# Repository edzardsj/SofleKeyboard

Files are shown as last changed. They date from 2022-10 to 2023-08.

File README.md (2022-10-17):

# Sofle Keyboard

## Internal Notes

 - [ ] Enable microcontroller with USB-C (possibly use a specific uC and redo the breakout on the PCB)
 - [ ] Use a scroll wheel (EVQ-WGD001) instead of a rotary encoder ([reference](https://oshwlab.com/ChristAlix/evqwgd001-roll-encoder_carrier-board_copy]) --- [KiCad model](https://github.com/crides/kleeb/blob/master/switch.pretty/EVQWGD001.kicad_mod))  
and add PCB mounting support
 - [ ] Add drilled holes to the PCB for more sophisticated case designs
 - [ ] Check button positioning + scroll wheel positioning / orientation on printed layout
 
 ## Vanilla docs

SofleKeyboard

Sofle is 6×4+5 keys column-staggered split keyboard with encoder support. Based on [Lily58](https://github.com/kata0510/Lily58), [Corne](https://github.com/foostan/crkbd) and [Helix](https://github.com/MakotoKurauchi/helix) keyboards.

**[For more information and documentation visit https://josefadamcik.github.io/SofleKeyboard/](https://josefadamcik.github.io/SofleKeyboard/)**

SofleKeyboard was created by [Josef Adamcik](https://josef-adamcik.cz/). The motivation and process is covered in following blog-post: [Let me introduce you SofleKeyboard - a split keyboard based on Lily58 and Crkbd](https://josef-adamcik.cz/electronics/let-me-introduce-you-sofle-keyboard-split-keyboard-based-on-lily58.html)

Sofle RGB was contributed by [Dane Evans](https://github.com/DaneEvans).

Sofle soldered was contributed by [kb-elmo](https://github.com/kb-elmo)

## Firmware 

Sofle uses [QMK firmware](https://qmk.fm/)

## Default layout 

Default layout for SofleKeyboard

## Images of keyboard

SofleKeyboard

SofleKeyboard Choc

SofleKeyboard PCB

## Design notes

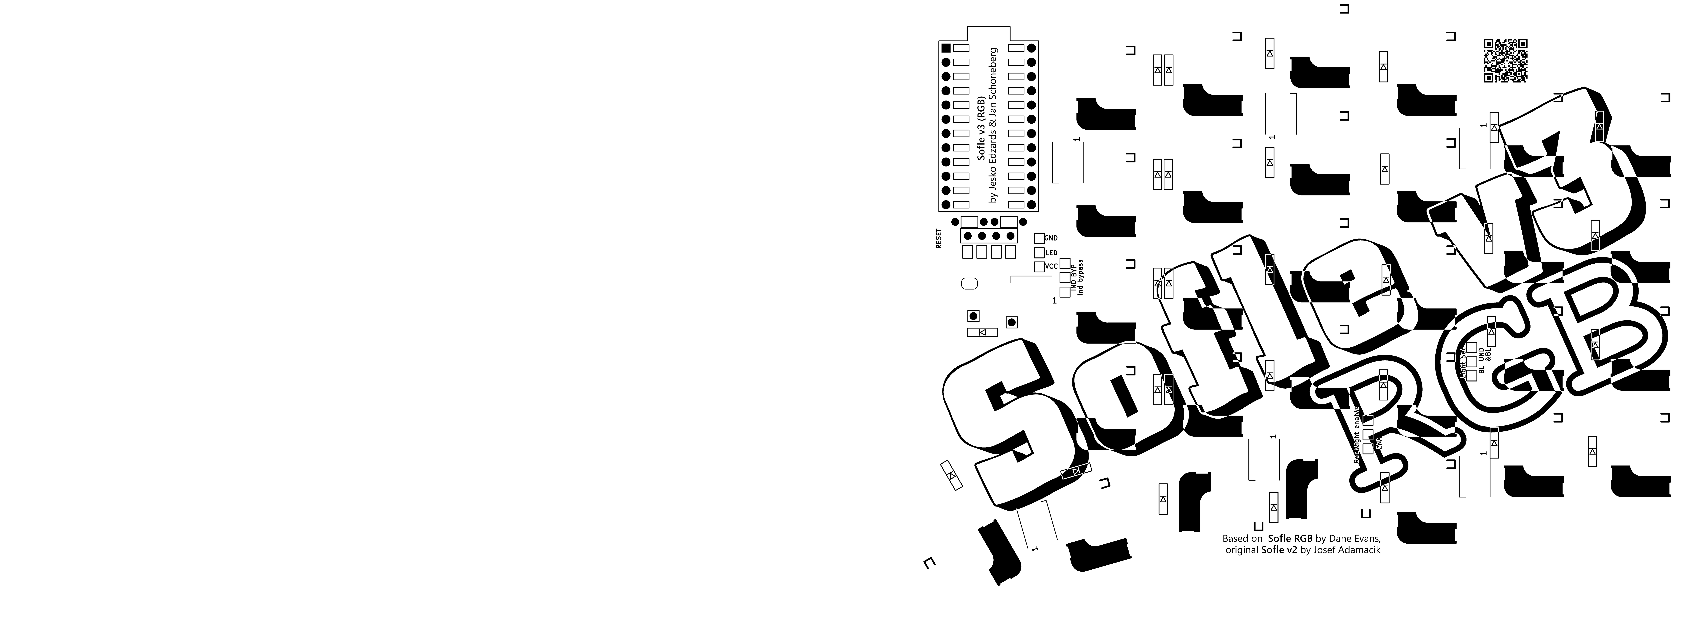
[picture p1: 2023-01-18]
Sofle_v3/silk screen design/Sofle_Front_final.png

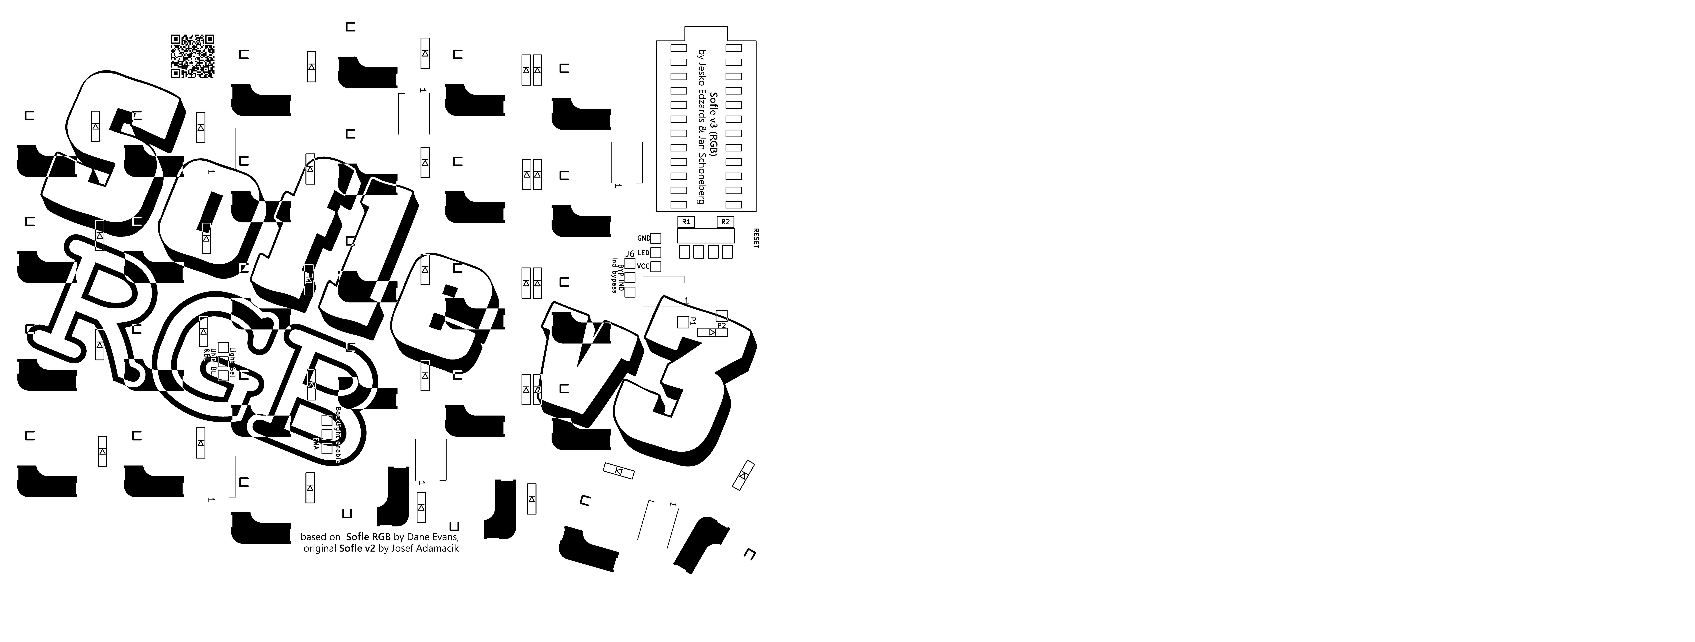
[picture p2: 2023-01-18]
Sofle_v3/silk screen design/Sofle_Back_final.png

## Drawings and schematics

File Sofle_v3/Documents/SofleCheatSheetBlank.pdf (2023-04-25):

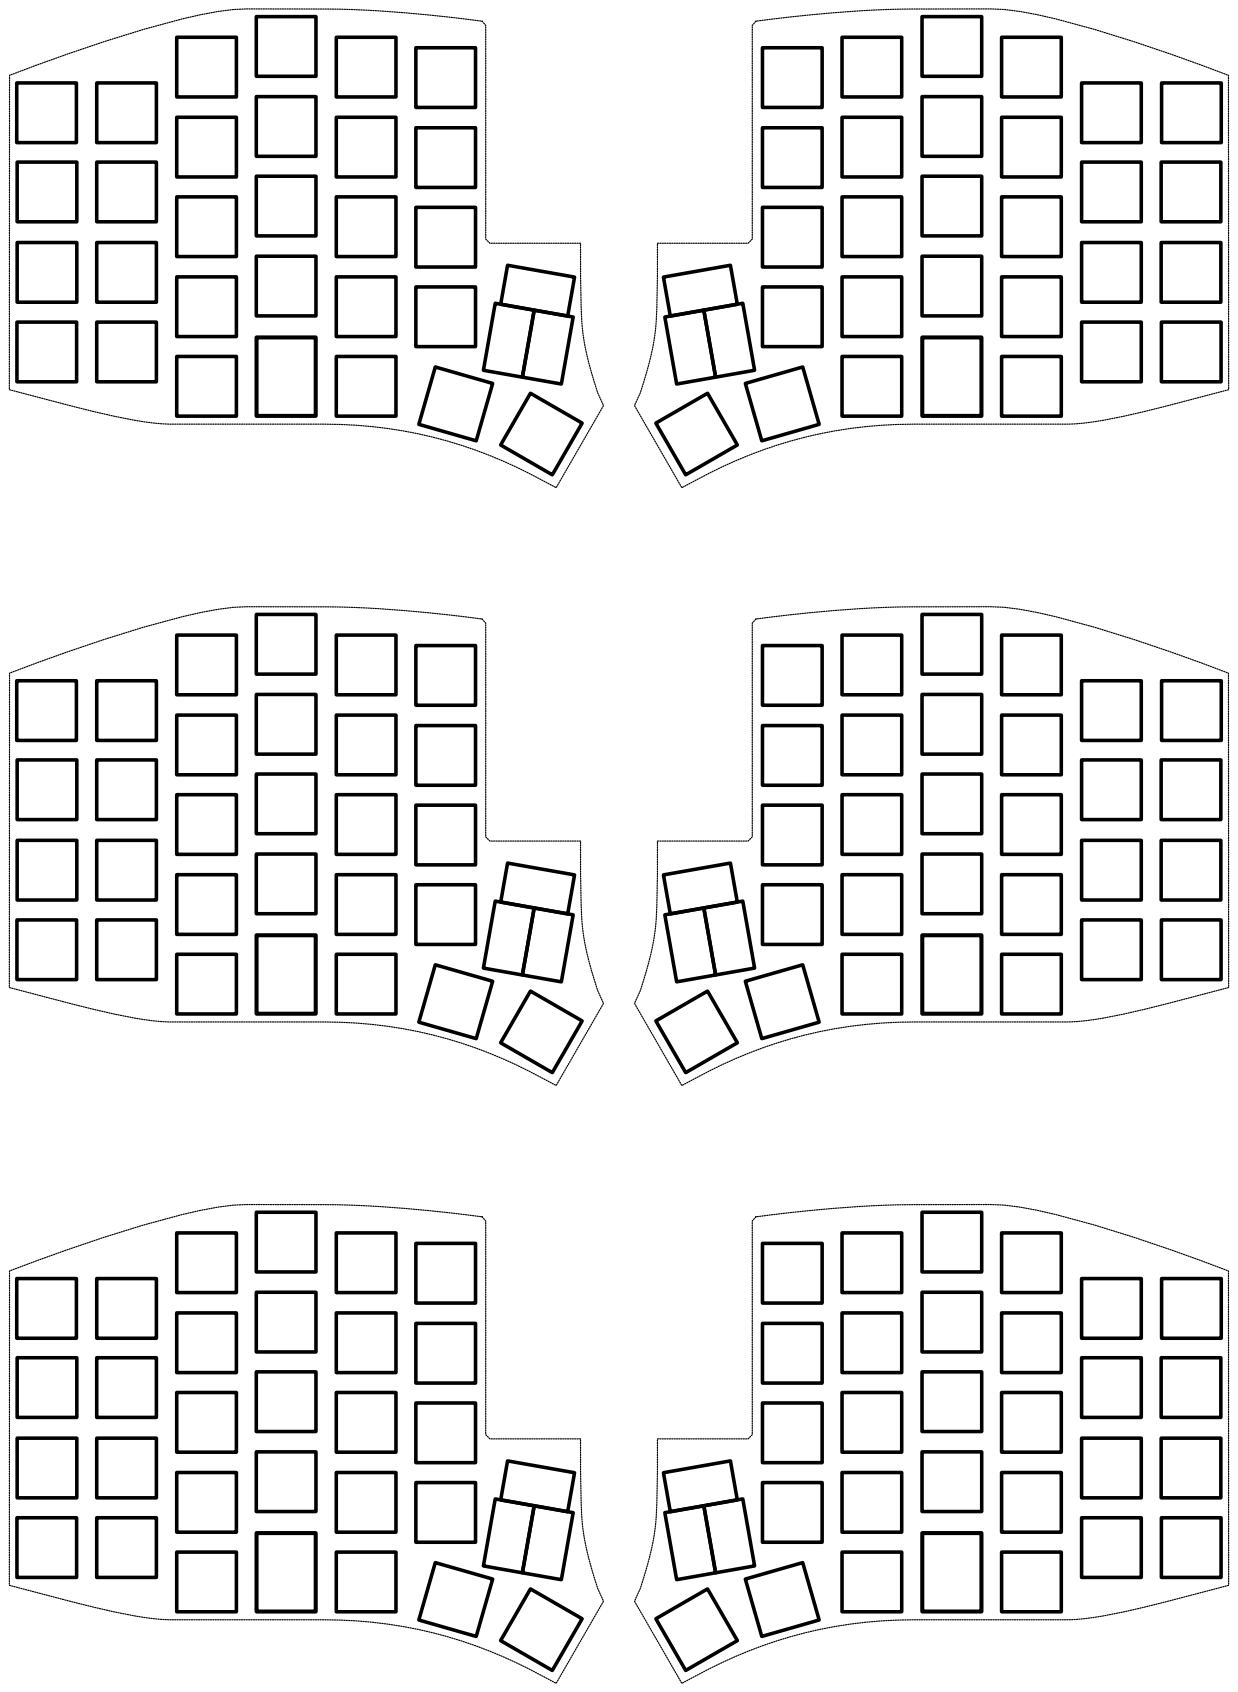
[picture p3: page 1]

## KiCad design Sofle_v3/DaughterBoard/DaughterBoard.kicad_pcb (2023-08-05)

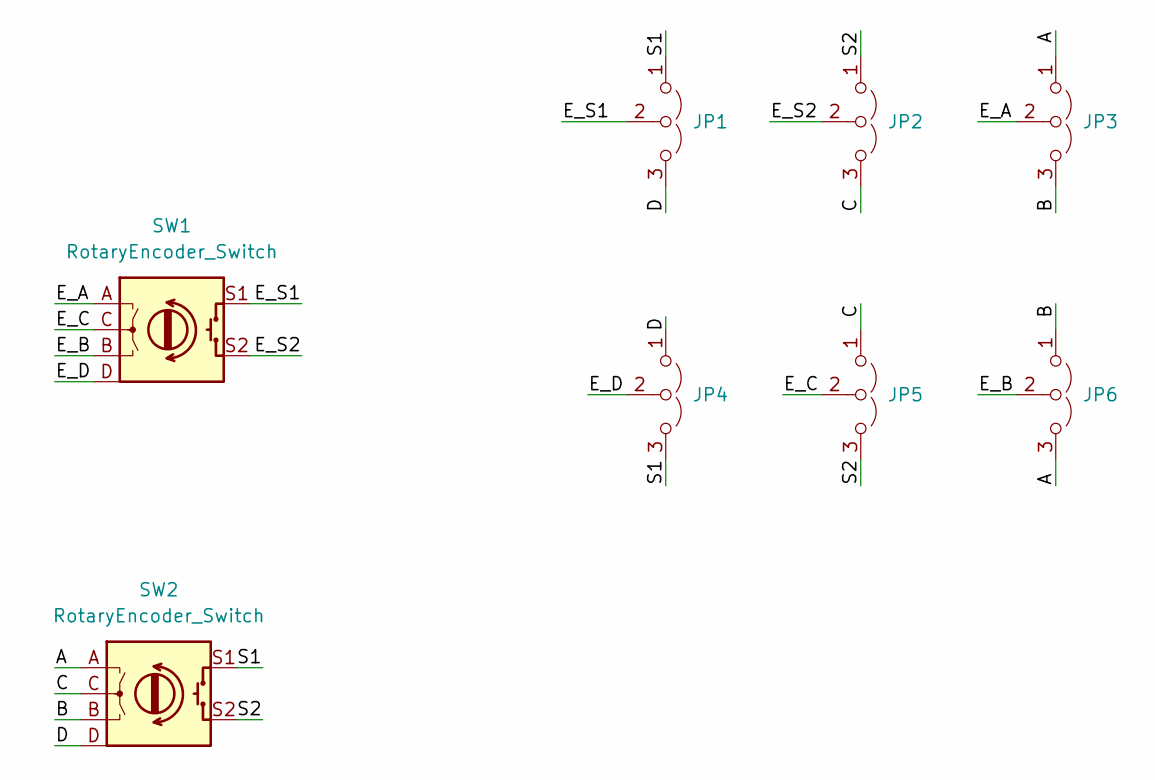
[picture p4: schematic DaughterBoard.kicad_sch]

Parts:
JP1, JP2, JP3, JP4, JP5, JP6: Jumper_3_Open; SolderJumper-3_P1.3mm_Open_Pad1.0x1.5mm
SW1: RotaryEncoder_Switch; EVQWGD001
SW2: RotaryEncoder_Switch; EVQWGD001_DaughterBoard_only

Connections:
/A: JP3.1 (A), JP6.3 (B), SW2.A
/B: JP3.3 (B), JP6.1 (A), SW2.B
/C: JP2.3 (B), JP5.1 (A), SW2.C
/D: JP1.3 (B), JP4.1 (A), SW2.D
/E_A: JP3.2 (C), SW1.A
/E_B: JP6.2 (C), SW1.B
/E_C: JP5.2 (C), SW1.C
/E_D: JP4.2 (C), SW1.D
/E_S1: JP1.2 (C), SW1.S1
/E_S2: JP2.2 (C), SW1.S2
/S1: JP1.1 (A), JP4.3 (B), SW2.S1
/S2: JP2.1 (A), JP5.3 (B), SW2.S2

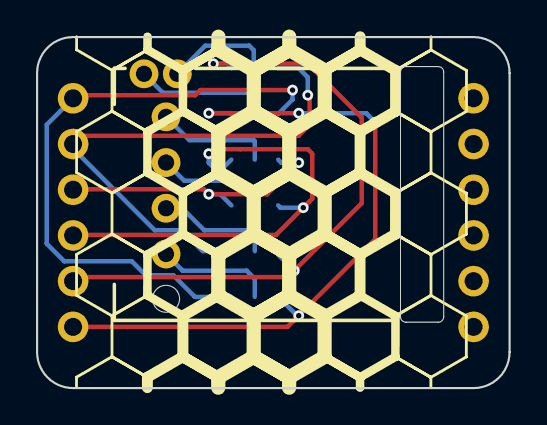
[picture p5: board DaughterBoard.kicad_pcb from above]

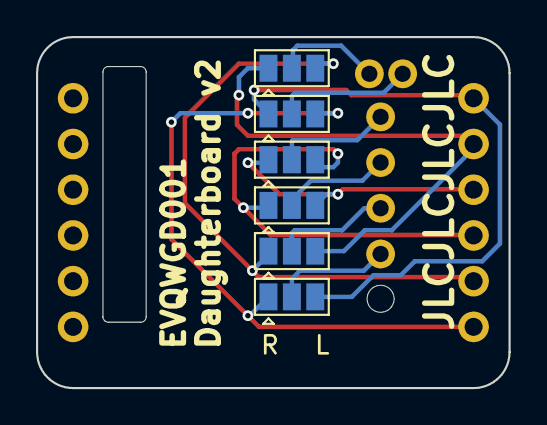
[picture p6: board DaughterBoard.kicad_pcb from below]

Board: 2 copper layers, 26.2 x 19.5 mm, 8 parts (6 on the bottom side), 12 nets.

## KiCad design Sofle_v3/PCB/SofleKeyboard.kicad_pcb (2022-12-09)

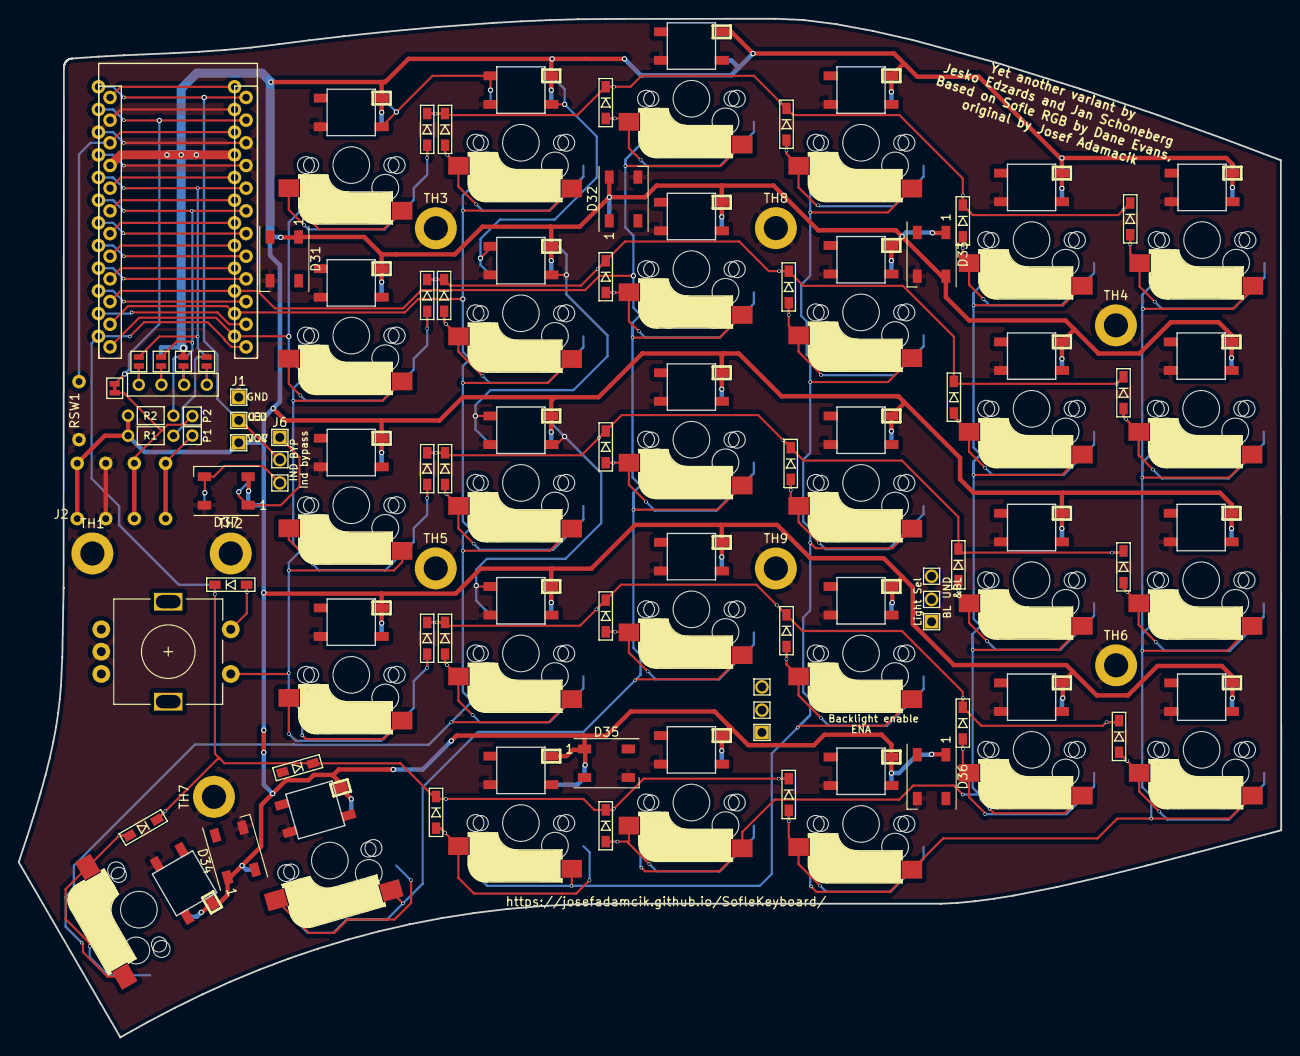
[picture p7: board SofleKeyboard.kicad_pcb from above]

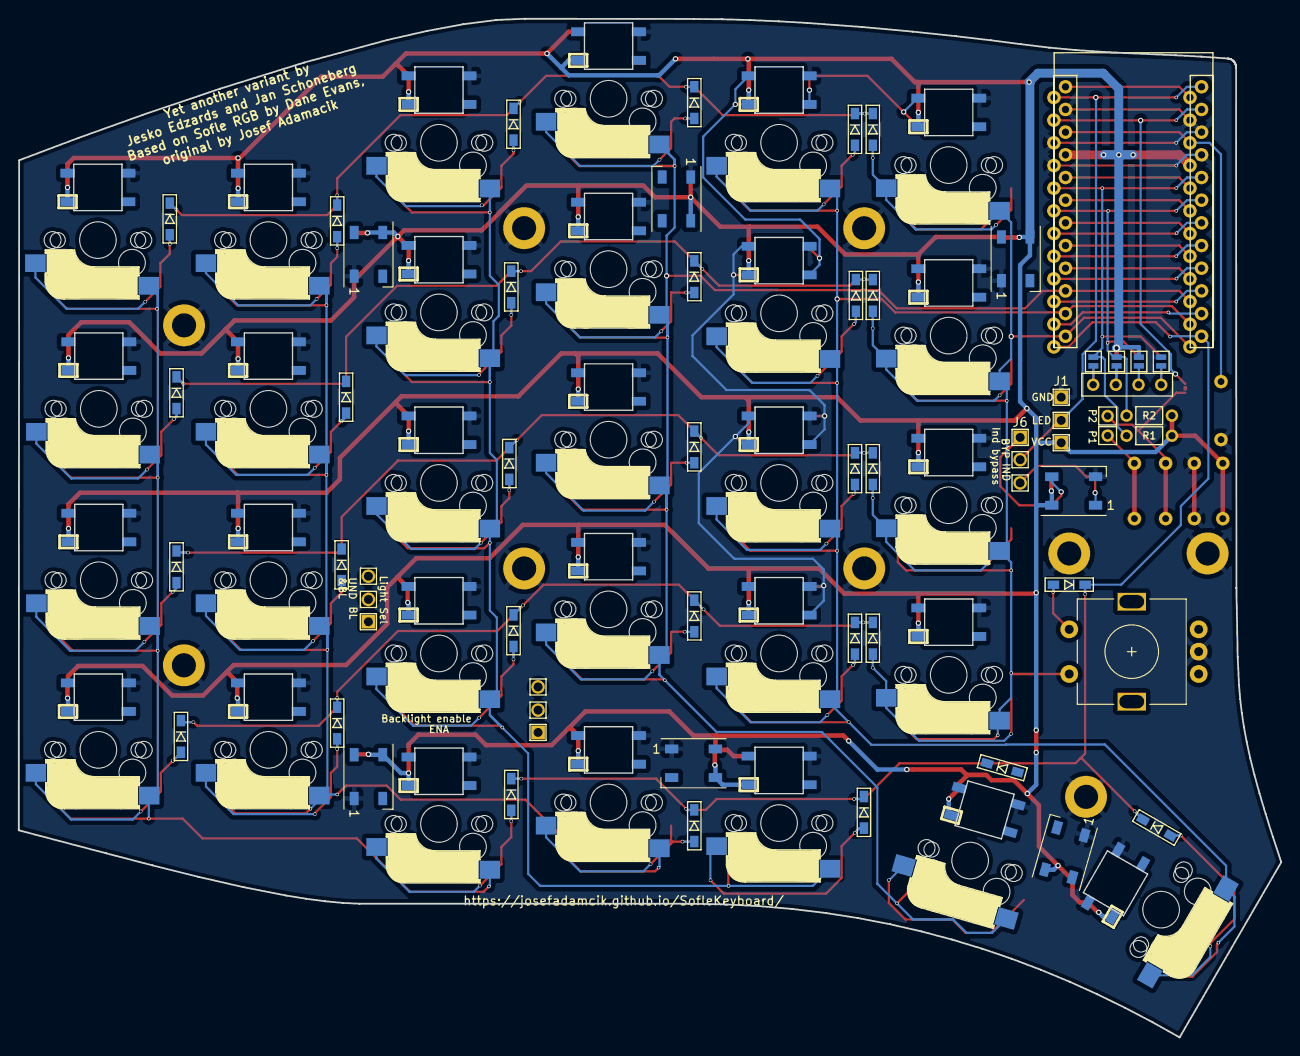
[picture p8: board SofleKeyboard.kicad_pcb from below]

Board: 2 copper layers, 141.4 x 114.1 mm, 97 parts (4 on the bottom side), 94 nets.

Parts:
D1, D2, D3, D4, D5, D6, D7, D8, D9, D10, D11, D12, D13, D14, D15, D16, D17, D18, D19, D20, D21, D22, D23, D24, D25, D26, D27, D28, D29, D30: D; crkbd-diode
D31, D32, D33, D34, D35, D36, D37: LED_sk2812_SM; LED_WS2812B_TwoSided
J1: LED
J2: 4PIN; WM2211210044
J3: OLED; OLED_4Pin
J4: key leds; 3x1header
J5: backlight sel; 3x1header
J6: indicator bypass; 3x1header
JP1, JP2, JP3, JP4, JP5, JP6, JP7, JP8: Jumper_NO_Small; Jumper
P1, P2: i2c_pin; 1pin_conn
R1, R2: R; RESISTOR_mini
RSW1: SW_RST; TPS635-1B43D
SW1, SW2, SW3, SW4, SW5, SW6, SW7, SW8, SW9, SW10, SW11, SW12, SW13, SW14, SW15, SW16, SW17, SW18, SW19, SW20, SW21, SW22, SW23, SW24, SW26, SW27, SW28, SW29, SW30: SW_PUSH-MX_W_LED; 5050_and_cherry
SW25: Rotary_Encoder_Switch; RotaryEncoder_Alps_EC11E-Switch_Vertical_H20mm-keebio_modif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
TH1, TH2, TH3, TH4, TH5, TH6, TH7, TH8, TH9: HOLE; MountingHole_2.7mm_M2.5_DIN965_Pad
U1: ProMicro
W1: jumper; jumper_data

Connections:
/SW1_D: D1.2 (A), SW1.5
/SW2_D: D2.2 (A), SW2.5
/SW3_D: D3.2 (A), SW3.5
/SW4_D: D4.2 (A), SW4.5
/SW5_D: D5.2 (A), SW5.5
/SW6_D: D6.2 (A), SW6.5
/SW7_D: D7.2 (A), SW7.5
/SW8_D: D8.2 (A), SW8.5
/SW9_D: D9.2 (A), SW9.5
/SW10_D: D10.2 (A), SW10.5
/SW11_D: D11.2 (A), SW11.5
/SW12_D: D12.2 (A), SW12.5
/SW13_D: D13.2 (A), SW13.5
/SW14_D: D14.2 (A), SW14.5
/SW15_D: D15.2 (A), SW15.5
/SW16_D: D16.2 (A), SW16.5
/SW17_D: D17.2 (A), SW17.5
/SW18_D: D18.2 (A), SW18.5
/SW19_D: D19.2 (A), SW19.5
/SW20_D: D20.2 (A), SW20.5
/SW21_D: D21.2 (A), SW21.5
/SW22_D: D22.2 (A), SW22.5
/SW23_D: D23.2 (A), SW23.5
/SW24_D: D24.2 (A), SW24.5
/SW25B: D25.2 (A), SW25.S2
/SW26_D: D26.2 (A), SW26.5
/SW27_D: D27.2 (A), SW27.5
/SW28_D: D28.2 (A), SW28.5
/SW29_D: D29.2 (A), SW29.5
/SW30_D: D30.2 (A), SW30.5
/backlight: J4.1, J5.1, SW30.2 (DIN)
/i2c_c: J2.4, P1.1
/i2c_d: J2.3, P2.1, W1.2
/underglow: D33.4 (DIN), J4.3
DATA: U1.2 (RX(PD2)), W1.1
ENCA: SW25.A, U1.20 (A3(PF4))
ENCB: SW25.B, U1.19 (A2(PF5))
GND: D31.3 (VSS), D32.3 (VSS), D33.3 (VSS), D34.3 (VSS), D35.3 (VSS), D36.3 (VSS), D37.4 (DIN), J1.3, J2.2, JP1.2, JP8.2, RSW1.1, SW1.3 (VSS), SW2.3 (VSS), SW3.3 (VSS), SW4.3 (VSS), SW5.3 (VSS), SW6.3 (VSS), SW7.3 (VSS), SW8.3 (VSS), SW9.3 (VSS), SW10.3 (VSS), SW11.3 (VSS), SW12.3 (VSS), SW13.3 (VSS), SW14.3 (VSS), SW15.3 (VSS), SW16.3 (VSS), SW17.3 (VSS), SW18.3 (VSS), SW19.3 (VSS), SW20.3 (VSS), SW21.3 (VSS), SW22.3 (VSS), SW23.3 (VSS), SW24.3 (VSS), SW25.C, SW26.3 (VSS), SW27.3 (VSS), SW28.3 (VSS), SW29.3 (VSS), SW30.3 (VSS), TH1.1, TH2.1, TH3.1, TH4.1, TH5.1, TH6.1, TH7.1, TH8.1, TH9.1, U1.3 (GND), U1.4 (GND), U1.23 (GND)
LED: J1.2, J6.2, U1.1 (TX(PD3))
unnamed: D31.2 (DOUT), D34.4 (DIN)
unnamed: D31.4 (DIN), D32.2 (DOUT)
unnamed: D32.4 (DIN), D33.2 (DOUT)
unnamed: D34.2 (DOUT), D35.4 (DIN)
unnamed: D35.2 (DOUT), D36.4 (DIN)
unnamed: D36.2 (DOUT), J5.2
unnamed: D37.3 (VSS), J6.3
unnamed: J3.1, JP4.1, JP8.1
unnamed: J3.2, JP3.1, JP7.1
unnamed: J3.3, JP2.1, JP6.1
unnamed: J3.4, JP1.1, JP5.1
unnamed: SW1.2 (DIN), SW2.4 (DOUT)
unnamed: SW1.4 (DOUT), SW7.2 (DIN)
unnamed: SW2.2 (DIN), SW8.4 (DOUT)
unnamed: SW3.2 (DIN), SW4.4 (DOUT)
unnamed: SW3.4 (DOUT), SW9.2 (DIN)
unnamed: SW5.2 (DIN), SW6.4 (DOUT)
unnamed: SW10.2 (DIN), SW16.4 (DOUT)
unnamed: SW4.2 (DIN), SW10.4 (DOUT)
unnamed: SW5.4 (DOUT), SW11.2 (DIN)
unnamed: SW11.4 (DOUT), SW17.2 (DIN)
unnamed: SW12.2 (DIN), SW18.4 (DOUT)
unnamed: SW6.2 (DIN), SW12.4 (DOUT)
unnamed: SW7.4 (DOUT), SW13.2 (DIN)
unnamed: SW13.4 (DOUT), SW19.2 (DIN)
unnamed: SW14.2 (DIN), SW20.4 (DOUT)
unnamed: SW8.2 (DIN), SW14.4 (DOUT)
unnamed: SW9.4 (DOUT), SW15.2 (DIN)
unnamed: SW15.4 (DOUT), SW21.2 (DIN)
unnamed: SW16.2 (DIN), SW22.4 (DOUT)
unnamed: SW17.4 (DOUT), SW23.2 (DIN)
unnamed: SW18.2 (DIN), SW24.4 (DOUT)
unnamed: SW20.2 (DIN), SW26.4 (DOUT)
unnamed: SW21.4 (DOUT), SW27.2 (DIN)
unnamed: SW22.2 (DIN), SW28.4 (DOUT)
unnamed: SW23.4 (DOUT), SW29.2 (DIN)
unnamed: SW24.2 (DIN), SW30.4 (DOUT)
unnamed: SW26.2 (DIN), SW27.4 (DOUT)
unnamed: SW28.2 (DIN), SW29.4 (DOUT)
RESET: RSW1.2, U1.22 (RST)
SCL: JP3.2, JP6.2, R2.2, U1.6 (SCL(PD0))
SDA: JP4.2, JP5.2, R1.2, U1.5 (SDA(PD1))
VCC: D31.1 (VDD), D32.1 (VDD), D33.1 (VDD), D34.1 (VDD), D35.1 (VDD), D36.1 (VDD), D37.2 (DOUT), J1.1, J2.1, JP2.2, JP7.2, R1.1, R2.1, SW1.1 (VDD), SW2.1 (VDD), SW3.1 (VDD), SW4.1 (VDD), SW5.1 (VDD), SW6.1 (VDD), SW7.1 (VDD), SW8.1 (VDD), SW9.1 (VDD), SW10.1 (VDD), SW11.1 (VDD), SW12.1 (VDD), SW13.1 (VDD), SW14.1 (VDD), SW15.1 (VDD), SW16.1 (VDD), SW17.1 (VDD), SW18.1 (VDD), SW19.1 (VDD), SW20.1 (VDD), SW21.1 (VDD), SW22.1 (VDD), SW23.1 (VDD), SW24.1 (VDD), SW26.1 (VDD), SW27.1 (VDD), SW28.1 (VDD), SW29.1 (VDD), SW30.1 (VDD), U1.21 (VCC)
col0: SW6.6, SW12.6, SW18.6, SW24.6, SW30.6, U1.18 (A1(PF6))
col1: SW5.6, SW11.6, SW17.6, SW23.6, SW29.6, U1.17 (A0(PF7))
col2: SW4.6, SW10.6, SW16.6, SW22.6, SW28.6, U1.16 (D15(PB1))
col3: SW3.6, SW9.6, SW15.6, SW21.6, SW27.6, U1.15 (D14(PB3))
col4: SW2.6, SW8.6, SW14.6, SW20.6, SW26.6, U1.14 (D16(PB2))
col5: SW1.6, SW7.6, SW13.6, SW19.6, SW25.S1, U1.13 (D10(PB6))
lights: D37.1 (VDD), J4.2, J6.1
row0: D1.1 (K), D2.1 (K), D3.1 (K), D4.1 (K), D5.1 (K), D6.1 (K), U1.8 (D5(PC6))
row1: D7.1 (K), D8.1 (K), D9.1 (K), D10.1 (K), D11.1 (K), D12.1 (K), U1.9 (D6(PD7))
row2: D13.1 (K), D14.1 (K), D15.1 (K), D16.1 (K), D17.1 (K), D18.1 (K), U1.10 (D7(PE6))
row3: D19.1 (K), D20.1 (K), D21.1 (K), D22.1 (K), D23.1 (K), D24.1 (K), U1.11 (D8(PB4))
row4: D25.1 (K), D26.1 (K), D27.1 (K), D28.1 (K), D29.1 (K), D30.1 (K), U1.12 (D9(PB5))

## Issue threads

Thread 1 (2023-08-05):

HW: Indicator LED footprint is mirrored

Freeviv, 2023-08-05:
**Which Board?**
Sofle_v3

**Which Board Revision?**
Beta version

**What is the issue?**
The footprint of the layer indicator LED is mirrored rendering it completely useless.

**What have you done to narrow down the issue?**
Look at the PCB

**What you expected:**

* [ ] Fix the PCB design

Freeviv, 2023-08-05:
Change not applied to PCB yet.

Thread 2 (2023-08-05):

HW: Silkscreen description for backlight LEDS is mirrored on one side of the PCB

Freeviv, 2023-08-05:
**Which Board?**
Sofle_v3

**Which Board Revision?**
Beta

**What is the issue?**
On one side of the PCB the silkscreen indicating the position of the LED's is mirrored.

**What have you done to narrow down the issue?**
Look at the PCB

**What you expected:**

* [ ] Change to combined footprint of keyswitch and LED to not have this inconsistency

Freeviv, 2023-08-05:
Commit [0212a15](https://github.com/edzardsj/SofleKeyboard/commit/0212a15df19c6126172d1063d670f3c22abb65bc) also includes a change that should fix this issue. Needs to be verified.

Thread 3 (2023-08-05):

HW: 3.5mm Jack quality issue

Freeviv, 2023-08-05:
**Which Board?**
Sofle_v3

**Which Board Revision?**
Beta

**What is the issue?**
The selected 3.5 mm jack has a poor connection quality making it annoying to use due to connection reliability issues.

**What have you done to narrow down the issue?**
Plugging in the 3.5mm cable. When connection issues occurs, tension the springs of the connector by pressing down on them

**What you expected:**

* [ ] Change the BOM of this PCB version to include a higher quality 3.5mm Jack

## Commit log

2022-12-08 design: base sofle RGB v3 pcb
    [SofleKeyboard.kicad_pcb, SofleKeyboard.kicad_sch, SofleKeyboard.sch]
2022-12-09 design: Added more footprints and symbols
2022-12-09 design: routing and schematic beatifications
    [SofleKeyboard.kicad_pcb, SofleKeyboard.kicad_sch]
2022-12-12 design: added/changed daughterboard footprint also added jumpers for rotatry encoder side switch
    [SofleKeyboard.kicad_sch]
2022-12-18 design: minor orientation change added daughterboard first drc checks
    [SofleKeyboard.kicad_sch]
2022-12-20 design rotated outer thumb key
    [SofleKeyboard.kicad_sch]
2022-12-26 design: add template for Silkscreen design
2022-12-29 design: removed cutout for daughter board + increased led distance
    [SofleKeyboard.kicad_sch]
2023-01-03 design: add left half for silkscreen design
2023-01-05 design: Moved uC down to not overlap edge cut Swapped wron DataIn with DataOut for WS2812B
2023-01-08 design: Daughter board - Redesign and added pcb project - Some 3d model shenanigans
    [DaughterBoard.kicad_pcb, DaughterBoard.kicad_sch, SofleKeyboard.kicad_sch]
2023-01-08 design: daughter board update
    [DaughterBoard.kicad_pcb, SofleKeyboard.kicad_sch]
2023-01-10 design: remove creators credit
    moved to custom silkscreen design
2023-01-15 design: replaced staggered uC design with solder jumpers
    [SofleKeyboard.kicad_sch]
2023-01-16 design: moved uC board 1mm down to make sure it does not stick out
2023-01-18 design(svg): finalize silkscreen design
2023-01-18 design: minor silkscreen corrections
2023-01-18 design: add custom back & front silkscreen
2023-01-18 design: add custom silkscreen design to main PCB
2023-01-21 production files added
    [DaughterBoard.kicad_pcb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]
2023-01-21 design: add silksceen design to daughterboard
    [DaughterBoard.kicad_pcb]
2023-02-26 Design: Fixed daughterboard pinout/Made it configurable
    [DaughterBoard.kicad_pcb, DaughterBoard.kicad_sch]
2023-05-14 fix: added adapter board for screwed up footprint
    [ConnectorBoard.kicad_pcb, ConnectorBoard.kicad_sch]
2023-08-05 [chore] Removed outdates gerber files.
    The gerber files should be considered binaries and do not need to be
    tracked in the git repository since they can easily be generated with
    the correct settings according to the PCB manifacturer of choice.
    [SofleKeyboard-B_Cu.gbl, SofleKeyboard-B_Mask.gbs, SofleKeyboard-B_Paste.gbp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]
2023-08-05 [fix] Fixed wrong Footprint for reset button and klinken connector
    Additionally updated files to new KiCad Version 7
    [SofleKeyboard.kicad_sch]
2023-08-05 [chore] Updated Project files to new KiCad version
    [ConnectorBoard.kicad_pcb]
2023-08-05 [Fix] Fixed wrong wiring of Daughter board
    To be precice, the main pcb has a wrong layout but it is cheaper
    and easier to fix the wiring on the daughter board. This is now
    how it alaways was meant to be ;)
    [DaughterBoard.kicad_pcb, DaughterBoard.kicad_sch]
2023-08-05 [Fix] Wrong inidicator for first pin
    This should fix issue #1
